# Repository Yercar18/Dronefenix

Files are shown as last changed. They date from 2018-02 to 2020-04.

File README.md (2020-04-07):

<!-- PROJECT SHIELDS -->
<!--
*** I'm using markdown "reference style" links for readability.
*** Reference links are enclosed in brackets [ ] instead of parentheses ( ).
*** See the bottom of this document for the declaration of the reference variables
*** for contributors-url, forks-url, etc. This is an optional, concise syntax you may use.
*** https://www.markdownguide.org/basic-syntax/#reference-style-links
-->

[][contributors-url]
[][forks-url]
[][stars-url]
[][issues-url]
[][license-url]
[][linkedin-url]

# Dronefenix
- Powered by arduino
N|Solid (https://arduino.cc)

<!-- TABLE OF CONTENTS -->
## Table of Contents

* [Getting Started](#Getting-Started)
* [List of Materials](#Materials)
* [Authors](#Authors)

# Getting Started

The steps to do this project is:

1. Adquire the materials (Includes the PCB or breadboard and wires).

2. Assembly the station [view schematic here](https://easyeda.com/miguelangelcu/dron_fenix) or [PCB]().

3. Install the [libraries](https://github.com/Yercar18/Dronefenix/tree/master/Librerias) -  [(how to) tutorial clicking here](https://www.youtube.com/watch?v=jMSic83Prs8).

4. Program the [arduino pro mini](https://github.com/Yercar18/Dronefenix/tree/master/airQ_Arduino) and [wemos d1](https://github.com/Yercar18/Dronefenix/tree/master/AirQ_Wemos).

5. Print your customized [case](https://github.com/Yercar18/Dronefenix/tree/master/case_3dPrinted).

6. Create the account on the [onmotica site](www.onmotica.com).

7. Have Fun, give us a start and share this project on your social networks, thanks!.

# Materials
| Name | Provider | Pricing (COP) |
| --- | --- |  --- |
| Arduino Nano V3 | [vistronica](https://www.vistronica.com/board-de-desarrollo/arduino/board/arduino-pro-mini-328-5v-16mhz-detail.html) | $ 10.782 |
| Wemos D1 Mini | [didacticas electronicas](https://www.didacticaselectronicas.com/index.php/comunicaciones/wi-fi/tarjeta-wemos-d1-mini-wifi-esp8266-wemosd1mini-wifi-internet-iot-detail) | $ 17.400 |
| SD Card Shield for Wemos | [didacticas electronicas](https://www.didacticaselectronicas.com/index.php/suiches-y-conectores/holders/shield-micro-sd-card-para-wemos-mini-d1-usd-wemos-sh-usd-holder-detail) | $ 7.000 |
| ASM1117 - 5V | [mercadolibre](https://articulo.mercadolibre.com.co/MCO-452253545-regulador-voltaje-5voltios-ams1117-superficial-arduino-_JM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) | $ 2.000 |
| ASM1117 - 3V3 | [mercadolibre](https://articulo.mercadolibre.com.co/MCO-523150391-10x-regulador-ams1117-33v-smd-_JM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) | $ 6.900 |
| Capacitor 470 uF-16V | [vistronica](https://www.vistronica.com/componentes-pasivos/capacitores/capacitor-electrolitico-de-aluminio-470uf-16v-8x12-mm-detail.html) | $ 193 |
| SMD LED | [vistronica](https://articulo.mercadolibre.com.co/MCO-533066032-diodos-led-smd-3535-6v-lg-_JM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) | $ 1.500 |
| SMD Resistor | [vistronica](https://www.vistronica.com/componentes-pasivos/resistencias/resistencias-4-7-kohm-smd-1206-14w-5-x10-detail.html) | $ 340 |
| Serial Level Shifter | [vistronica](https://www.vistronica.com/comunicaciones/serial/modulo-conversor-de-nivel-logico-de-5v-a-3-3v-3-3v-a-5v-detail.html) | $ 2.056 |
| I2C Level Shifter | [vistronica](https://www.didacticaselectronicas.com/index.php/semiconductores/drivers-y-conversores/convertidor-de-nivel-l%C3%B3gico-bidireccional-pca9306-conversor-convertidor-c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) | $ 30.200 |
| CCS 811 | [vistronica](https://www.didacticaselectronicas.com/index.php/sensores/ambientales/sensor-de-calidad-del-aire-sensor-calidad-de-aire,-ccs811,-ntc-co2-eco2-tvoc-monoxiodo-de-carbono-interiores-detail) | $58.000 |
| GPS Neo 6M | [vistronica](https://www.vistronica.com/comunicaciones/modulo-gps-gy-neo6mv2-con-memoria-eeprom-detail.html) | $ 39.000 |
| DHT 11 | [vistronica](https://www.vistronica.com/sensores/modulo-sensor-de-temperatura-y-humedad-dht11-detail.html) | $ 5.454 |
| MQ-135 | [vistronica](https://www.didacticaselectronicas.com/index.php/sensores/gases/modulo-sensor-de-gas-mq-135-sensor-de-gas-gases-benzeno-amoniaco-dioxido-de-carbono-nh3-co2-mq135-mq-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) | $ 9.000 |
| MQ-4 | [vistronica](https://www.didacticaselectronicas.com/index.php/sensores/gases/modulo-sensor-para-gas-metano-cng-mq-4-sensor-gas-gases-metano-mq4-mq-4-seeed-studio-detail) | $ 7.800 |
| BMP-180 | [vistronica](https://www.didacticaselectronicas.com/index.php/sensores/presion-atm/sensor-de-presion-atmosferica-bmp180-presion-relativa-barometro-bmp180-detail) | $ 9.600 |

## library required before install 
- [Adrafruit sensor](https://github.com/adafruit/Adafruit_Sensor)
- [Adafruit_CCS811](https://github.com/adafruit/Adafruit_CCS811)
- [SFE_BMP180](https://github.com/sparkfun/BMP180_Breakout)
- [TinyGPS](https://github.com/mikalhart/TinyGPS)
- [DHT](https://github.com/adafruit/DHT-sensor-library)
Note: 
3.0 version has all libs in library folder.

Dronefenix is an open source project that seeks the implementation of a datalogger on a drone for efficient environmental sampling.

  1. Download the github project.
  2. Install the libraries in the arduino software.
  3. Upload the code to your arduino mega card.
  4. Take off and perform your personal measurements.

# New Features!

  - Updated, now are using MQSensor lib 2.0.1

  - Add gas sensor ccs 811 to allow detection of contaminants (05/02/2018)

You can also:
  - Obtain measurements of temperature, humidity, atmospheric pressure, heat index, GPS coordinates of the point where these data were measured.
  - Measure the degree of contamination. new!! 

Through this implementation you will be able to quickly observe the status of your crops, constantly monitor a large area, among others. 

### Third-party librarys

Dronefenix uses a number of open source projects to work properly:

* [TinyGPS] - Excelent for gps Apps!
* [DHT-sensor-library] - From adafruit.com to read DHT11.
* [BMP180_Breakout] - A great librarie to read BMP180 Sensor.
* [Adafruit_CCS811] - Best librarie for CCS811 Sensor.

And of course Dronefenix itself is open source with a https://github.com/Yercar18/Dronefenix/

### Installation

Dronefenix requires [Arduino ide](https://arduino.cc/)  to run.

Install the libraries.

To install a new library into your Arduino IDE you can use the Library Manager (available from IDE version 1.6.2).
Open the IDE and click to the "Sketch" menu and then Include Library > Manage Libraries.

# Authors
* **Miguel A. Califa U.** - [*GitHub*](https://github.com/miguel5612) - [CV](https://scienti.colciencias.gov.co/cvlac/visualizador/generarCurriculoCv.do?cod_rh=0000050477)
* **Yersson Ramiro Carrillo Amado** - [*GitHub*](https://github.com/yercar18) - [CV](https://scienti.colciencias.gov.co/cvlac/visualizador/generarCurriculoCv.do?cod_rh=0001637655)

# License
----

MIT

<!-- MARKDOWN LINKS & IMAGES -->
<!-- https://www.markdownguide.org/basic-syntax/#reference-style-links -->
[contributors-shield]: https://img.shields.io/github/contributors/Yercar18/Dronefenix.svg?style=flat-square
[contributors-url]: https://github.com/Yercar18/Dronefenix/graphs/contributors
[forks-shield]: https://img.shields.io/github/forks/Yercar18/Dronefenix.svg?style=flat-square
[forks-url]: https://github.com/Yercar18/Dronefenix/network/members
[stars-shield]: https://img.shields.io/github/stars/Yercar18/Dronefenix.svg?style=flat-square
[stars-url]: https://github.com/Yercar18/Dronefenix/stargazers
[issues-shield]: https://img.shields.io/github/issues/Yercar18/Dronefenix.svg?style=flat-square
[issues-url]: https://github.com/Yercar18/Dronefenix/issues
[license-shield]: https://img.shields.io/github/license/Yercar18/Dronefenix.svg?style=flat-square
[license-url]: https://github.com/Yercar18/Dronefenix/blob/master/LICENSE.txt
[linkedin-shield]: https://img.shields.io/badge/-LinkedIn-black.svg?style=flat-square&logo=linkedin&colorB=555
[build-url]: https://travis-ci.org/dwyl/esta.svg?branch=master
[linkedin-url]: https://www.linkedin.com/in/miguel5612
[product-screenshot]: images/screenshot.png

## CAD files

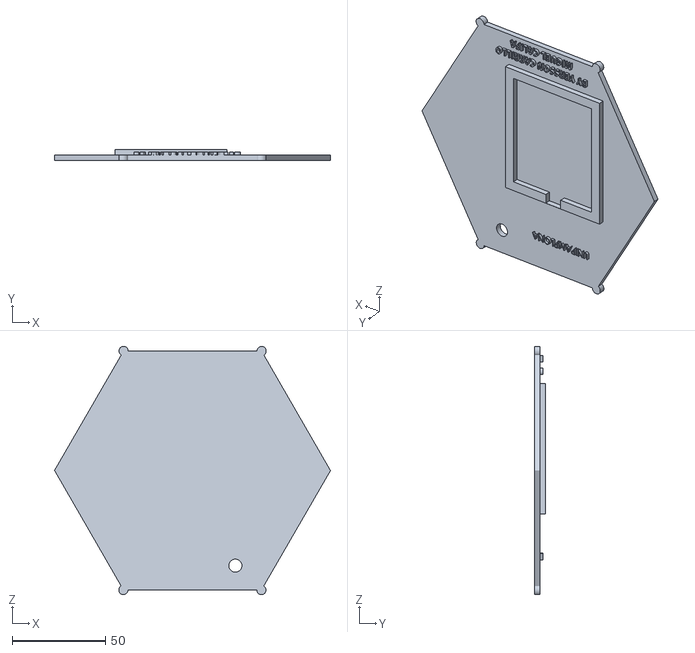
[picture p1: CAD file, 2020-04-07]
case_3dPrinted/case_estacion22.STL
148.0 x 6.00 x 133.2

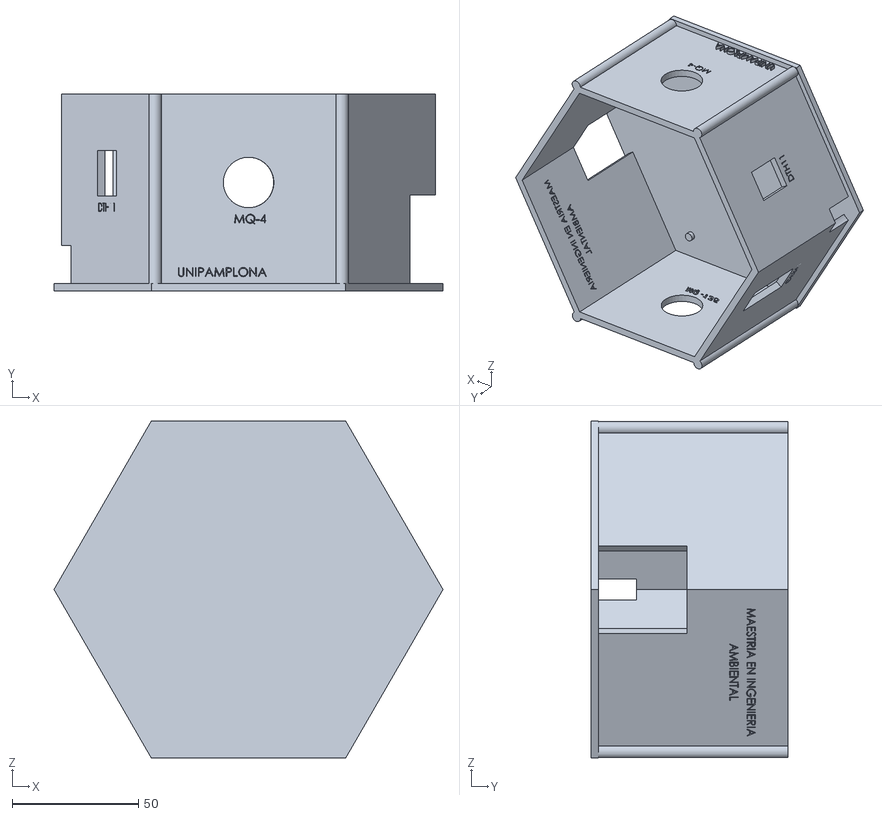
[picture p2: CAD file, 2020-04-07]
case_3dPrinted/case_estacion11.STL
154.0 x 78.0 x 133.4

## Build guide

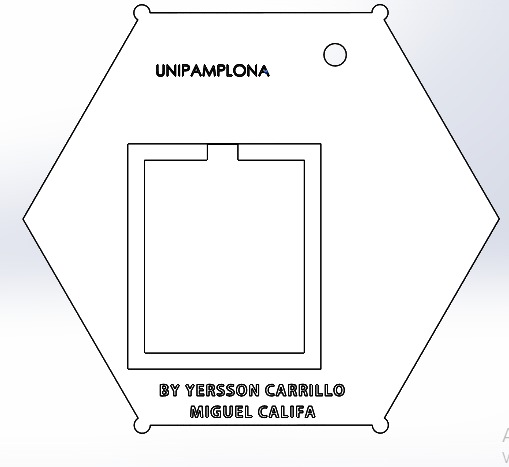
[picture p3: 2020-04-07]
case_3dPrinted/preview/top2.jpeg

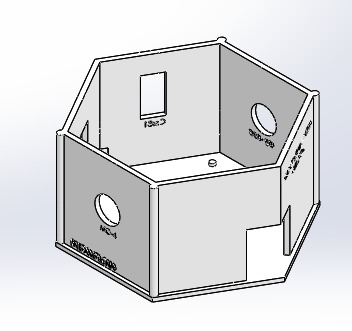
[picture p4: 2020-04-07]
case_3dPrinted/preview/main.jpeg

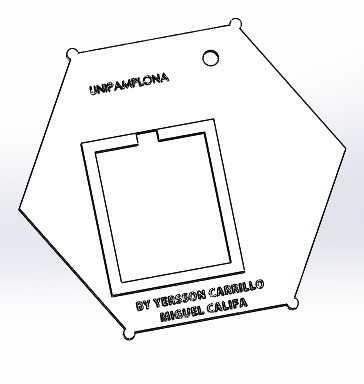
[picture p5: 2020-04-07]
case_3dPrinted/preview/top.jpeg

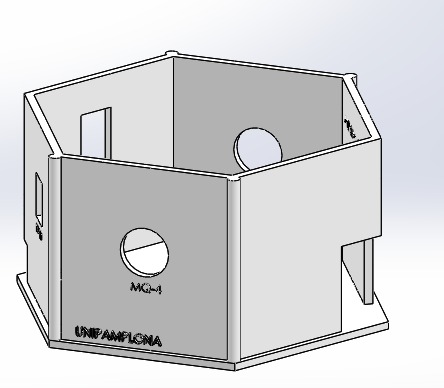
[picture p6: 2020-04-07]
case_3dPrinted/preview/main_rotated.jpeg

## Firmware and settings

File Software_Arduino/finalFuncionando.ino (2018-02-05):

/*
  ENSAMBLE DE UN DRONE BASADO EN UN SISTEMA SENSORIAL Y MULTIESPECTRAL PARA MEDIR VARIABLES  METEOROLÓGICOS
  Este programa permite generar un archivo excel en el cual
  se ven reflejados la temperatura , humedad , presion atmosferica
  y la geolocalizacion ( latitud , longitud en la cual se encuentra el dispositivo ).


   Materiales

  - SD CARD SHIELD
  - Arduino Mega Protoshield
  - Arduino Mega R3
  - Sensor CCS811

   Cableado
  Gps TX --> Arduino Mega RX 3
  Gps RX --> Arduino Mega TX 3
  BMP 180 conexion I2C , SDA and SCL.
  DHT 11 --> Pin 7 Arduino Mega
  ** El cableado de la sd shield deben modificarlo para que se acople al arduino mega pines 50,51,52  SD shield 11,12,13


  created 06 June 2016
  by Yerson Carrillo in collaboration with Miguel Angel Califa Urquiza
  modified 14 January 2017
  by Miguel Califa
  redesigned to redistribution

*/

//Importacion libreria - librarie import

#include <SPI.h>
#include <SoftwareSerial.h>
#include <TinyGPS.h>
#include "DHT.h"
#include <SFE_BMP180.h>
#include <Wire.h>
#include <SD.h>
#include "Adafruit_CCS811.h"

//Variables globales - globale variables
long consecutivo = 0;
float hum, ic, alt;
double temp, p;
String fecha ;
char status;
double T, P, p0, a;
float h, t, f, hif, hic;
int co2, tvoc, tempCCS;
const int ledWarning = 5 ; //** LED QUE INDICA ERRORES **//
const int dispCam = A0; //Pin que dispara la camara para tomar una foto , Pin that triggers the camera to take a picture.
const int gpsTxPin =  9;
const int gpsRxPin =  8;
Adafruit_CCS811 ccs;
#define DHTPIN 7



//Variables especiales de la libreria del Gps - special variables of gps

static void smartdelay(unsigned long ms);
static void print_float(float val, float invalid, int len, int prec);
static void print_int(unsigned long val, unsigned long invalid, int len);
static void print_date(TinyGPS &gps);
static void print_str(const char *str, int len);

//inicializacion de librerias globales

TinyGPS gps;
File Archivo;
#define DHTTYPE DHT11   // DHT 11
SFE_BMP180 pressure;
DHT dht(DHTPIN, DHTTYPE);

void setup() {


  //Declaracion I/O de pines
  pinMode(dispCam, INPUT);
  pinMode(10, OUTPUT);
  pinMode(ledWarning, OUTPUT);


  //inicializacion de los puertos serie para comunicarse con los perifericos - computador - GPS
  Serial.begin(115200);
  Serial3.begin(9600);
  if (!ccs.begin()) {
    Serial.println("Failed to start sensor! Please check your wiring.");
    while (1);
  }

  //Aviso del encendido


  bienvenida();


  //incicializacion del modulo sd
  if (!SD.begin(10)) {
    Serial.println("INICIALIZACION DE SD FALLO!");
    while (1) {
      digitalWrite(ledWarning, HIGH);
      delay(500);
      digitalWrite(ledWarning, LOW);
      delay(500);
    }
    return;
  }

  //Aviso de que todo ha inicializado correctamente

  Serial.println("INIT OK "); // Esto lo puedes personalizar

  // deteccion de errores - intentar abrir el archivo para verificar que existe
  Archivo = SD.open("datos.csv", FILE_WRITE);
  if (Archivo) {
    //Archivo.write("Temperatura barometrico ; Humedad ; Presion absoluta ; Indice de calor ; latitud ; Logitud ; Altitud ; fecha;");
    Archivo.println(" ");

  } else {
    digitalWrite(ledWarning, HIGH);
    delay(500);
    digitalWrite(ledWarning, LOW);
    delay(500);
  }
  Archivo.close();

  // inicializacion del dht para medir temperatura y humedad relativa - prueba de errores en perifericos de medicion

  dht.begin();

  if (pressure.begin())
    Serial.println("BMP180 init success"); // aviso de la inicializacion exitosa del bmp 180
  else
  {

    Serial.println("BMP180 Error\n\n");
    while (1) {
      digitalWrite(ledWarning, HIGH);
      delay(250);
      digitalWrite(ledWarning, LOW);
      delay(250);

      // Pausa por siempre y alerta de fallo personalizada
    }
  }

inicioDeAlmacenamiento();
}
// final del setup , hasta aqui todos los perifericos estan armados y preparados para actuar en el momento que se necesiten

void loop()
{

  //este ciclo se repite n veces para grabar cada una de las mediciones

  //**VARIABLES DE USO EN LA EJECUCION DEL PROGRAMA**//
  float flat, flon;
  unsigned long age, date, time, chars = 0;
  unsigned short sentences = 0, failed = 0;
  static const double LONDON_LAT = 51.508131, LONDON_LON = -0.128002;

  // Obtener las geolocalizaciones en las variables flat y flon

  gps.f_get_position(&flat, &flon, &age);
  gps.stats(&chars, &sentences, &failed);

  //validacion de las lecturas del gps , sino estas en un sitio cubierto por un satelite no puedo registrar los datos

  if ((flat == 1000 && flon == 1000)  ) { //flat!=1000 && flon!=1000 // CAMBIO PARA TEST EN SD


    Serial.println("Error leyendo el gps por que esta en una zona donde no recibe señal");
    for (int i = 0; i <= 2; i++) {

      digitalWrite(ledWarning, HIGH);
      delay(50);
      digitalWrite(ledWarning, LOW);
      delay(50);
    }
  }  else {
    digitalWrite(ledWarning, HIGH);
  }


  Serial.println();
  Serial.println();

  //el delay de siempre se reemplaza por un smart delay para realizar otras operaciones necesarias


  smartdelay(1000);
  if (analogRead(dispCam) > 800) {
    if (digitalRead(ledWarning) == 0) {
      digitalWrite(ledWarning, HIGH);
    } else {
      digitalWrite(ledWarning, LOW);
    }
    print_date(gps);
    print_float2(gps.f_altitude(), TinyGPS::GPS_INVALID_F_ALTITUDE, 7, 2);

    //LEO LOS DATOS
    leerDatos(flat, flon);
    //PUBLICO POR MEDIO DE LOS PERIFERICOS EXISTENTES(MONITOR SERIE)
    publicar(flat, flon);
    //ALMACENO EN MEMORIA SD

    almacenarDatos(flat, flon);

    Serial.println();
    Serial.println("Esperando GPS");
    Serial.println();
  }

}

//funciones de usuario independientes , invocadas durante la ejecucion del loop

void inicioDeAlmacenamiento(){
  Archivo = SD.open("datos.csv", FILE_WRITE);
  if (Archivo) {
    Archivo.print("------------------------------------------------ INICIO DE LA TOMA DE DATOS -------------------------------------------------");
    Archivo.println();
    
    Archivo.print("Temperatura");
    Archivo.print(";");

    Archivo.print("Humedad");
    Archivo.print(";");

    Archivo.print("Presion");
    Archivo.print(";");

    Archivo.print("Indice de calor");
    Archivo.print(";");


    Archivo.print("Latitud");
    Archivo.print(";");

    Archivo.print("Longitud");
    Archivo.print(";");

    Archivo.print("Altitud");
    Archivo.print(";");

    
    Archivo.print("Nivel de CO2 PPB");
    Archivo.print(";");
    
    Archivo.print("Niveles de TVOC PPB");
    Archivo.print(";");
    
    Archivo.print("Temperatura reportada por el CCS");
    Archivo.print(";");

  

    Archivo.print("Fecha/hora de la muestra");
    Archivo.println(";");


  }
}


void almacenarDatos(float flat2 , float flon2) {

  //** CONSTANTES temp,hum,p,ic; **///

  Archivo = SD.open("datos.csv", FILE_WRITE);
  if (Archivo) {
    Archivo.print(temp);
    Archivo.print(";");

    Archivo.print(hum);
    Archivo.print(";");

    Archivo.print(p);
    Archivo.print(";");

    Archivo.print(ic);
    Archivo.print(";");


    Archivo.print(flat2, 6);
    Archivo.print(";");

    Archivo.print(flon2, 6);
    Archivo.print(";");

    Archivo.print(alt);
    Archivo.print(";");

    
    Archivo.print(co2);
    Archivo.print(";");
    
    Archivo.print(tvoc);
    Archivo.print(";");
    
    Archivo.print(tempCCS);
    Archivo.print(";");

  

    Archivo.print(fecha);
    Archivo.println(";");




  } else {
    digitalWrite(ledWarning, HIGH);
    delay(500);
    digitalWrite(ledWarning, LOW);
    delay(500);
  }
  Archivo.close();

}




void leerDatos(float flat , float flon) {

  status = pressure.startTemperature();
  if (status != 0)
  {
    delay(status);
    status = pressure.getTemperature(T);
    if (status != 0)
    {
      //Serial.print("Esta es la temperatura actual: ");
      //Serial.print(T,2);
      //Serial.println("");

      //*** GUARDANDO EN LA VARIABLE GLOBAL ***//

      temp = T;

      //*** FIN DEL GUARDADO EN MEMORIA **//


      status = pressure.startPressure(3);

      if (status != 0)
      {
        delay(status);


        status = pressure.getPressure(P, T);

        if (status != 0)
        {

          //Serial.print("Esta es la presion absoluta medida por el bmp180 :  ");
          //Serial.print(P,2);
          //Serial.println("");

          //***ALMACENANDO EN VARIABLE GLOBAL **//
          p = P;

        }
        else {}
      }
      else {}
    }
    else {}
  }
  else {}

  leerTemperatura(flat, flon);
  leerCCS();

}
void leerCCS() {
  if (ccs.available()) {
    float temp = ccs.calculateTemperature();
    if (!ccs.readData()) {

      co2 = ccs.geteCO2();
      tvoc = ccs.getTVOC();
      tempCCS =  temp;

    }

  }
}
  void leerTemperatura(float flat , float flon)
  {



    h = dht.readHumidity();

    t = dht.readTemperature();

    f = dht.readTemperature(true);


    if (isnan(h) || isnan(t) || isnan(f)) {
      Serial.println("fallo leyendo el sensor DHT11!");
      return;
    }


    hif = dht.computeHeatIndex(f, h);

    hic = dht.computeHeatIndex(t, h, false);

    //**** ALMACENANDO EN MEMORIA ****///

    ic = hic;
    hum = h;


  }

  void publicar(float latitud, float longitud) {

    consecutivo++;

    Serial.print("****************** ");
    Serial.print(consecutivo);
    Serial.println(" ******************");

    Serial.print("Reporte de datos numero : ");
    Serial.println(consecutivo);

    Serial.print("Fecha actual internacional : ");
    Serial.println(fecha);

    Serial.print("latitud: ");
    Serial.println(latitud, 8);

    Serial.print("longitud: ");
    Serial.println(longitud, 8);


    //****LECTURA DE LA HUMEDAD **//

    Serial.print("Este es la temperatura actual  :   ");
    Serial.print(temp);
    Serial.println("  °C");


    h = dht.readHumidity();

    //****LECTURA DE LA HUMEDAD **//

    Serial.print("Este es la humedad actual  :   ");
    Serial.print(h);
    Serial.println(" %");

    ///** LECTURA DEL INDICE DE CALOR**//

    Serial.print("Este es el inidce de calor actual :   ");
    Serial.println(hic);



    Serial.print("Esta es la presion absoluta medida por el bmp180 :  ");
    Serial.print(P, 2);
    Serial.println("");

    Serial.print("Estas son las lecturas del CCS811:  ");

    Serial.print("CO2: ");
    Serial.print(co2);
    Serial.print("ppm, TVOC: ");
    Serial.print(tvoc);
    Serial.print("ppb   Temp:");
    Serial.println(tempCCS);
    Serial.println("");


    Serial.print("-------------------");
    Serial.print("");
    Serial.print(consecutivo);
    Serial.println("--------------------");

    Serial.println();

    Serial.println();

  }
  void bienvenida() {
    Serial.println(); Serial.println(); Serial.println();
    Serial.print("ENSAMBLE DE UN DRONE BASADO EN UN SISTEMA SENSORIAL Y MULTIESPECTRAL PARA MEDIR VARIABLES  METEOROLÓGICOS v.1.0 ");
    Serial.println("Yerson Carrillo And Miguel Califa");
    Serial.println();
    Serial.println();
    Serial.print("Lic : 2016 ");

    Serial.println();

  }
  // Funciones para uso unico del GPS , importante no tocar! - Agradecimiento a TinyGPS por estas funciones.



  static void smartdelay(unsigned long ms)
  {
    unsigned long start = millis();
    do
    {
      while (Serial3.available()) {
        gps.encode(Serial3.read());
      }
      if (analogRead(dispCam) > 800) {
        ms = millis() - start - 10; // garantizo que se interrumpe si hay disparo
      }

    } while (millis() - start < ms);


  }


  static void print_float(float val, float invalid, int len, int prec)
  {
    if (val == invalid)
    {
      while (len-- > 1)
        Serial.print('*');
      //Serial.print(';');
    }
    else
    {
      Serial.print(val, prec);
      int vi = abs((int)val);
      int flen = prec + (val < 0.0 ? 2 : 1); // . and -
      flen += vi >= 1000 ? 4 : vi >= 100 ? 3 : vi >= 10 ? 2 : 1;
      for (int i = 1; i > 1; ++i)
        Serial.print(' ');
    }
    smartdelay(0);
    Serial.print(';');
  }

  static void print_float2(float val, float invalid, int len, int prec)
  {
    if (val == invalid)
    {
      while (len-- > 1)
        Serial.print('*');
      //Serial.print(';');
    }
    else
    {
      //Serial.print(val, prec);
      alt = val ; //**GUARDO LA altitud **//
      int vi = abs((int)val);
      int flen = prec + (val < 0.0 ? 2 : 1); // . and -
      flen += vi >= 1000 ? 4 : vi >= 100 ? 3 : vi >= 10 ? 2 : 1;
      for (int i = 1; i > 1; ++i)
        Serial.print(' ');
    }
    smartdelay(0);
    //Serial.print(';');
  }
  static void print_int(unsigned long val, unsigned long invalid, int len)
  {
    char sz[32];
    if (val == invalid)
      strcpy(sz, "*******");
    else
      sprintf(sz, "%ld", val);
    sz[len] = 0;
    for (int i = strlen(sz); i < len; ++i)
      sz[i] = ';';
    if (len > 0)
      sz[len - 1] = ';';
    Serial.print(';');
    smartdelay(0);
  }

  static void print_date(TinyGPS & gps)
  {
    int year;
    byte month, day, hour, minute, second, hundredths;
    unsigned long age;
    gps.crack_datetime(&year, &month, &day, &hour, &minute, &second, &hundredths, &age);
    if (age == TinyGPS::GPS_INVALID_AGE)
      Serial.print("********** ********");
    else
    {
      char sz[32];
      sprintf(sz, "%02d/%02d/%02d %02d:%02d:%02d ",
              month, day, year, hour, minute, second);
      //Serial.print("la fecha de hoy es :   ");
      //Serial.print(sz);
      //Serial.println();
      fecha = sz;//**GUARDO EN MEMORIA LA FECHA
    }
    //print_int(age, TinyGPS::GPS_INVALID_AGE, 5);
    smartdelay(0);
  }

  static void print_str(const char *str, int len)
  {
    int slen = strlen(str);
    for (int i = 0; i < len; ++i)
      Serial.print(i < slen ? str[i] : ';');
    smartdelay(0);
  }

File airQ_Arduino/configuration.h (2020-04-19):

#ifndef CONFIGURATION_H
#define CONFIGURATION_H

#include "Arduino.h"

//Area de configuracion del DHT11
#define DHTPIN 8
// Uncomment whatever type you're using!
#define DHTTYPE DHT11   // DHT 11
//#define DHTTYPE DHT22   // DHT 22  (AM2302), AM2321
//#define DHTTYPE DHT21   // DHT 21 (AM2301)

//Area de configuracion del CCS
#define CCS811_ADDR 0x5A //Default I2C Address

//Area de configuracion de los sensores MQ
#define MQ4Pin A1
#define MQ135Pin A0
#define arduino_sample_rate 1024
#define decPrecision 7

//Area de configuracion del GPS y de la comunicacion entre arduino y wemos
#define gpsRx 6
#define gpsTx 7
#define wRx 10
#define wTx 11
#define baudRateGps 9600
#define baudRateDebug 115200
#define serDebug true

//Configuracion para el envio de informacion (AVANZADO)
#define initialCharacter "Inicio"
#define endCharacter "Final"
#define sep ","

//Tiempos de espera..
#define timeDelay 500
#define limit 10 //rango -- entre 6 y 12
#define limitTime 10*1000 // 5 minutos en milisegundos


#endif // CONFIGURATION_H

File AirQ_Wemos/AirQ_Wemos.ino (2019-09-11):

#include "SERIAL_COMMUNICATION.h"
#include "PROCESS_DATA.h"
#include "SD_PROCESS.h"
#include "WIFI_PROCESS.h"
#include "MEMORY_ADMINISTRATION.h"
#include "PINS.h"
#include "configuration.h"

#include <ESP8266WiFi.h>
#include <PubSubClient.h>
//needed for library
#include <DNSServer.h>
#include <ESP8266WebServer.h>

SERIAL_COMMUNICATION serial;
PROCESS_DATA procesamiento;
SD_PROCESS memoriaSD;
WIFI_PROCESS WiFiProcess;
MEMORY_ADMINISTRATION administracion;
PINS pinesIO;

static const int count_mqtt_server = 3;
static char* mqtt_server[count_mqtt_server] = { "mqtt.onmotica.com", "mqtt2.onmotica.com", "mqtt3.onmotica.com"};
char* __mqttServerConnected;
const int serverPort = 1883;
int serverConnectedIndex = 0;

unsigned long lastPublishedTime = 0;
unsigned long lastGetPetition = 0;


WiFiClient espClient;
PubSubClient mqttClient(espClient);

void setup() {

    //Inicializacion de los pines, memoria SD y WiFi
    pinesIO.inicializar();
    memoriaSD.setFileCounter(0);
    memoriaSD.setNumError(0);
    
    serial.inicializar();
    memoriaSD.inicializar();
    memoriaSD.guardarEncabezados();

    WiFiProcess.inicializar();

    //Guardo en el registro que el sistema inicio correctamente
    memoriaSD.saveIntoLogMsg("Encendido del sistema, WiFi OK", administracion.freeSpaceReportSerial() , WiFiProcess.wifiIsConnected()?"Conectado":"Desconectado", mqttIsConnected()?"Conectado":"Desconectado", false);

    String resultPetition = WiFiProcess.getPetition(URL);
    if(serDebug) Serial.println("Peticion get - " + resultPetition);
    
    setMQTTServer();

    procesamiento.setTimeToWait(procesamiento.generateRandom());
    memoriaSD.saveIntoLogMsg("Saliendo del setup - Resultado de la peticion: " + resultPetition, administracion.freeSpaceReportSerial() , WiFiProcess.wifiIsConnected()?"Conectado":"Desconectado", mqttIsConnected()?"Conectado":"Desconectado", false);
    
}


void loop() {
  
    if(!WiFiProcess.wifiIsConnected()) setup(); //Reinicio si no hay wifi
    if (!mqttIsConnected()) reconnect(); //Reconectar mqtt si perdio conexion

    String informacion = serial.leerArduino();
    if(procesamiento.procesarInformacion(informacion))
    {
      //Calcular y guardar la fecha
      String fecha = memoriaSD.getTime();
      procesamiento.setFecha(fecha);
      //Si la informacion es valida se debe proceder a guardar en la SD y enviar al MQTT server
      String lineaSDCard = procesamiento.mensajeSDTabulado();
      memoriaSD.guardarInfo(lineaSDCard);
      if(serDebug) Serial.println("Guardado en la sd: " + lineaSDCard);
      
      //Mensaje MQTT
      double temperatura = procesamiento.leerTemperatura();
      double humedad = procesamiento.leerHumedad();
      double presionAmosferica = procesamiento.leerPresionAtmosferica();
      int tvoc =  procesamiento.leerTVOC();
      int co2 = procesamiento.leerCO2();
      int alcohol = procesamiento.leerAlcohol();
      int CH4 = procesamiento.leerCH4();
      int NH4 = procesamiento.leerNH4();
      float latitud = procesamiento.leerLatitud();
      float longitud = procesamiento.leerLongitud();

      String json2MQTT = procesamiento.ensamblarMensajeJSON(temperatura, humedad, presionAmosferica, alcohol, tvoc, co2, CH4, NH4, latitud, longitud, fecha);
      
      if(procesamiento.SAVEJSON(json2MQTT))
      {
        procesamiento.setTimeToWait(procesamiento.generateRandom());
        sendMQTTMsgPacket(procesamiento.getIndex());
      }

    }
    
    if((millis() - lastPublishedTime)>maxTimeWithNoPublish)  memoriaSD.saveIntoLogMsg("Han pasado " + String(maxTimeWithNoPublish/60000) + " minutos sin enviar actualizaciones" , administracion.freeSpaceReportSerial() , WiFiProcess.wifiIsConnected()?"Conectado":"Desconectado", mqttIsConnected()?"Conectado":"Desconectado", true);   
    if((millis() -lastGetPetition)>maxTimeWithNoPublish) WiFiProcess.getPetition(URL); //Despertar al servidor haciendo una peticion cada media hora
    mqttClient.loop();
}
void sendMQTTMsgPacket(int countMsgToSend)
{
  int len = 260;
  char buf[len];
  procesamiento.resetMsgQeueCounter();
  for(int i=0; i<=countMsgToSend; i++)
  {    
    String mensajeJson = procesamiento.getJSON(i);
    mensajeJson.toCharArray(buf, len);
    savePublishStatusMQTT(publicarInformacion(buf));
  }
}
void savePublishStatusMQTT(boolean result)
{
  if(result)
      { 
         unsigned long span = (millis() - lastPublishedTime)/1000;
         int ratio = span>60?span/60:span;
         String unidad = span>60?" minutos":" segundos";
         lastPublishedTime = millis();
         memoriaSD.saveIntoLogMsg("Mensaje publicado(" + String(__mqttServerConnected) + ") con exito - ratio (Tiempo transcurrido desde la anterior publicacion): " + String(ratio) + unidad , administracion.freeSpaceReportSerial() , WiFiProcess.wifiIsConnected()?"Conectado":"Desconectado", mqttIsConnected()?"Conectado":"Desconectado", false);   
      }
      else
      {
        memoriaSD.saveIntoLogMsg("Mensaje no publicado", administracion.freeSpaceReportSerial() , WiFiProcess.wifiIsConnected()?"Conectado":"Desconectado", mqttIsConnected()?"Conectado":"Desconectado", true);   
      }
}


boolean publicarInformacion(char JSON[260]){
   
    bool isPublished = false;
    int attemps = 0;

    while(!isPublished & attemps<=10)
    {
      if (mqttClient.publish(inTopic, JSON) == true) {        
        isPublished = true;
        if(serDebug) Serial.println("El mensaje se ha publciado correctamente");        
        if(serDebug) Serial.println("Publicado!!! :)");
        break;
      } else {
        attemps++;
        if(serDebug) Serial.println("No se ha podido publicar - intento " + String(attemps));
        if(serDebug) Serial.println("Mensaje no publicado: " + String(JSON));
        isPublished = false;
        delay(minTime);
      }
    }
    delay(minTime);
    return isPublished;
}

void setMQTTServer()
{   
  if(serverConnectedIndex < count_mqtt_server-1)
  {
    serverConnectedIndex++;
  }
  else
  {
    serverConnectedIndex = 0;
  }
  __mqttServerConnected = mqtt_server[serverConnectedIndex];//"broker.mqtt-dashboard.com";
  if(serDebug) Serial.println("MQTT Server: " + String(__mqttServerConnected));
  mqttClient.setServer(__mqttServerConnected, serverPort);
  mqttClient.setCallback(callback);
}
bool mqttIsConnected()
{
  return mqttClient.connected();
}
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

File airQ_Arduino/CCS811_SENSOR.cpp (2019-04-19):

#include <Wire.h>

#include "CCS811_SENSOR.h"
#include "SparkFunCCS811.h"
//#include "configuration.h"

CCS811 mySensor(0x5A);

String CCS811_SENSOR::inicializar(){
  Wire.begin();
  CCS811Core::status returnCode = mySensor.begin();
  
  if (returnCode != CCS811Core::SENSOR_SUCCESS)
  {
    Serial.println("CCS Reporta error");
    while (1); //Hang if there was a problem.
  }
  return "CCS811 OK";
  //return ccs.begin()?"CCS Ok":"CCS Init Fail";  
}
void CCS811_SENSOR::cicloCCS()
{
  if (mySensor.dataAvailable()) {
    mySensor.readAlgorithmResults();
    __co2 = mySensor.getCO2();
    __tvoc = mySensor.getTVOC();
    __flag = true;
  }
}
double CCS811_SENSOR::medirCO2(){
  return __co2;
}

double CCS811_SENSOR::medirTVOC(){
  return __tvoc;
}

bool CCS811_SENSOR::getFlagVal(){
  return __flag;
}
void CCS811_SENSOR::resetFlag(){
  __flag = false;
}

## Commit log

2018-02-05 se añade el sensor de gases para identificar la cortina emanada
2018-02-18 Se añade el folder con las librerias necesarias para compilar y hacer funcionar el Software_Arduino
2018-02-18 Se añade automatica consecusion de archivos, es decir si existe datos 1 comienza a escribir en datos2
2018-02-18 Se corrige el problema con las cabeceras del archivo
2018-02-18 Se reparan las unidades en las que se retorna el puerto serie
2018-02-18 Se realizan las pruebas de calibracion
    [DATOS12.CSV, DATOS13.CSV, DATOS16.CSV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]
2018-06-13 Added Gerber for CNC Print
    [Gerber_BoardOutline.GKO, Gerber_BottomLayer.GBL, Gerber_BottomSolderMaskLayer.GBS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]
2018-07-04 Se reemplaza el diseño de EasyEda a proteus
    [Gerber_BoardOutline.GKO, Gerber_BottomLayer.GBL, Gerber_BottomSolderMaskLayer.GBS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]
2018-08-15 Se publica la segunda version de la estacion metereologica y la primera version se almacena independiente
    [DATOS12.CSV, DATOS13.CSV, DATOS16.CSV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]
2018-08-16 Se modifica el codigo del arduino uno para que transmita siempre una trama de 53 caracteres y se publica el codigo del arduino numero 2
2018-08-17 Se realizan modificaciones en la comunicacion entre los arduinos
2018-08-17 Se agrega un separador entre el string de entrada y el de publicacion
2018-09-27 Se agrega la version 3.0
2018-09-27 Se reemplaza la declaracion de las variables
2018-09-27 Se agrega el codigo del datalogger y la pagina web
2018-09-27 fixed led error
2018-10-04 changed i2c --> serial
2018-10-05 Arduino code Finished - started wemo code
2018-10-08 Update testing wemo and arduino comm
2018-10-12 Updated programming to new circuit design
2019-01-02 Se agrega la latitud, longitud y la fecha a los datos enviados por mqtt
2019-04-16 Added new version with more ordered files
    [configuration.h]
2019-04-17 Se publica la version 1
    [configuration.h]
2019-04-17 Replaced serDebug for serialprinln if serdebug flag
    [AirQ_Wemos.ino, MQTT_PROCESS.cpp, SD_PROCESS.cpp]
2019-04-17 Fixed save error into sd
    [configuration.h]
2019-04-18 REmoved unused string 2 double fction
    [configuration.h]
2019-04-18 Ended arduno code
    [configuration.h]
2019-04-18 Added comments into config file
    [configuration.h]
2019-04-18 Modificados los caracteres de inicio y fin
    [configuration.h]
2019-04-18 Added methods and sd
    [configuration.h]
2019-04-18 Fixed data invalida error false
    [AirQ_Wemos.ino, PROCESS_DATA.cpp]
2019-04-18 Fixed problem when compile mqtt process
    [configuration.h]
2019-04-18 Change mqtt selection process
    [configuration.h]
2019-04-18 Fix char width problem
    [AirQ_Wemos.ino, PROCESS_DATA.cpp, SD_PROCESS.cpp]
2019-04-18 Added ratio to log
    [configuration.h]
2019-04-18 Fixed payload spaces
    [configuration.h]
2019-04-18 Fixed DHT22 to DHT11
    [configuration.h]
2019-04-18 Published v5.000 as final
    [DATOS12.CSV, DATOS13.CSV, DATOS16.CSV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]
2019-04-19 only two brokers at now
    [AirQ_Wemos.ino]
2019-04-20 Multiple modifications on publish
    [configuration.h]
2019-04-27 Changed mqtt settings
    [configuration.h]
2019-08-23 Updated libraries, added MQ Unified sensor and removed old code
2019-09-08 Fixed lecture Alcohol and CH4, NH4
    [PROCESS_DATA.cpp, airQ_Arduino.ino]
2019-09-11 Customized pub-sub client library
    [configuration.h]
2020-04-07 Added pictures and STL
    [case_estacion11.STL, case_estacion22.STL]
2020-04-07 added print task
2020-04-19 Updated refresh time
    [configuration.h]

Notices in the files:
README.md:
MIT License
